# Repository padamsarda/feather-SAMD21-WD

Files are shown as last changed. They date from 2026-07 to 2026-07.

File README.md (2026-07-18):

# Feather SAMD21 MAX637X Watchdog dev board

A Feather-compatible development board based on the ATSAMD21G18A microcontroller with an integrated MAX6373 hardware watchdog for improving system reliability. The board retains the Adafruit Feather M0 Express footprint and pinout while incorporating USB Type-C connectivity, Li-Po battery charging, USB protection, and external clock circuitry. A 555 monostable circuit enables MCU power cycling, while multiple jumper options allow sections of the watchdog and reset circuitry to be enabled, disabled, or bypassed as required.

### Board at a glance

| Category | Hardware |
|---|---|
| MCU | ATSAMD21G18A |
| Hardware Watchdog | MAX6373 |
| USB | USB Type-C with USBLC6-2SC6 ESD protection |
| Battery Charging | MCP73832 |
| Voltage Regulation | AP2112K-3.3 (×2), LM5155xMM |
| Clock | 32.768 kHz crystal oscillator |
| Power Cycling | 555 monostable circuit |
| Expansion | Feather-compatible headers |

## MCU-WD Architecture

<p align="center">
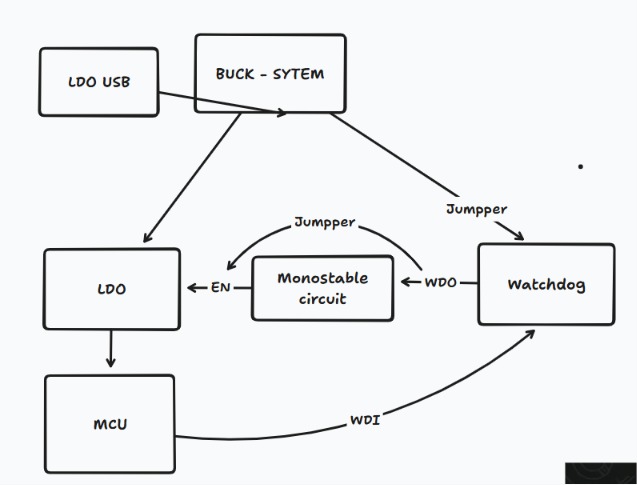
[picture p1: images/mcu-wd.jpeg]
MCU-WD Architecture
  <br>
  <em>High-level architecture of the Feather SAMD21 Watchdog board.</em>
</p>

## Schematic

Schematic

## PCB

<p align="center">
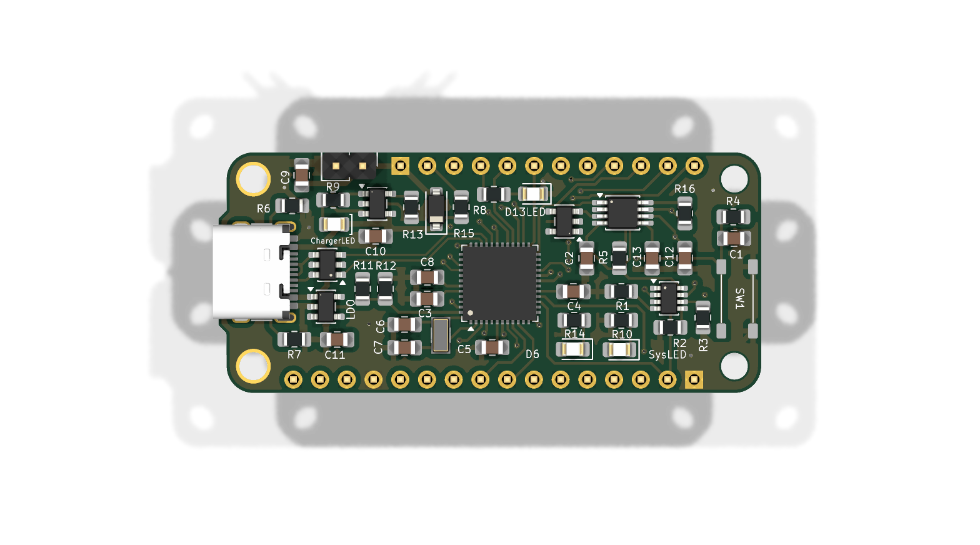
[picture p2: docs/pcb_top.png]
PCB Top
  
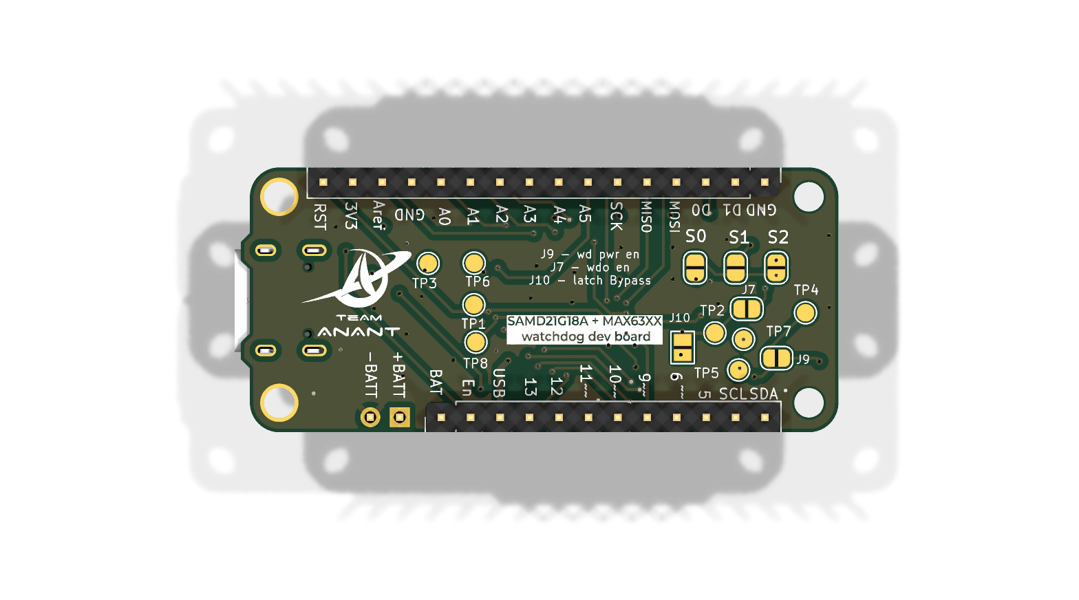
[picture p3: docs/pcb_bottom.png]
PCB Bottom
  
</p>

## Key Components

| Reference | Part | Function |
|---|---|---|
| U3 | ATSAMD21G18A-MU | Main microcontroller |
| U8 | MAX6373 | Hardware watchdog supervisor |
| U5 | MCP73832 | Li-Po battery charger |
| U2 | USBLC6-2SC6 | USB ESD protection |
| U4, U6 | AP2112K-3.3 | 3.3 V regulators |
| U7 | LM5155xMM | Power regulation |
| X1 | 32.768 kHz Crystal | External RTC clock source |
| D3 | BAT43W | Schottky diode |
| D2 | LED | Status indication |

## Connectors & I/O

| Reference | Interface | Description |
|---|---|---|
| J1 | JumperSET0 | Watchdog configuration |
| J2 | JumperSET1 | Watchdog configuration |
| J3 | JumperSET2 | Watchdog configuration |
| J4 | Left Feather Header | Feather-compatible expansion |
| J5 | Right Feather Header | Feather-compatible expansion |
| J6 | Battery Header | Li-Po battery connection |
| J7 | Reset Enable Jumper | Enable/disable reset path |
| J8 | USB Type-C | USB interface |
| J9 | WD_PWR Jumper | Watchdog power control |
| J10 | Monostable Bypass Jumper | Bypass 555 power-cycle circuit |

Designed and developed as part of **Team Anant**.

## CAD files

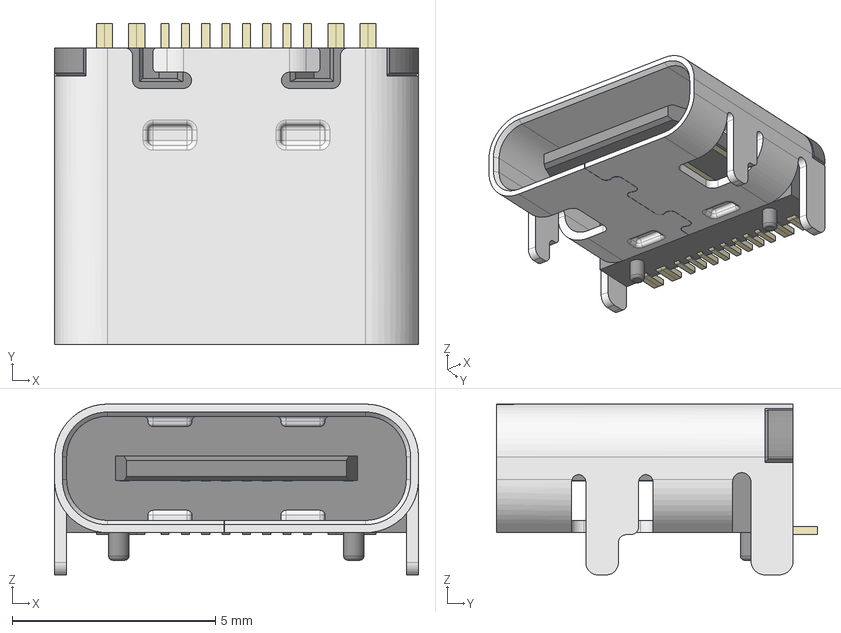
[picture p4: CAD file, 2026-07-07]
HRO_TYPE-C-31-M-12.step
8.95 x 7.90 x 4.20 mm

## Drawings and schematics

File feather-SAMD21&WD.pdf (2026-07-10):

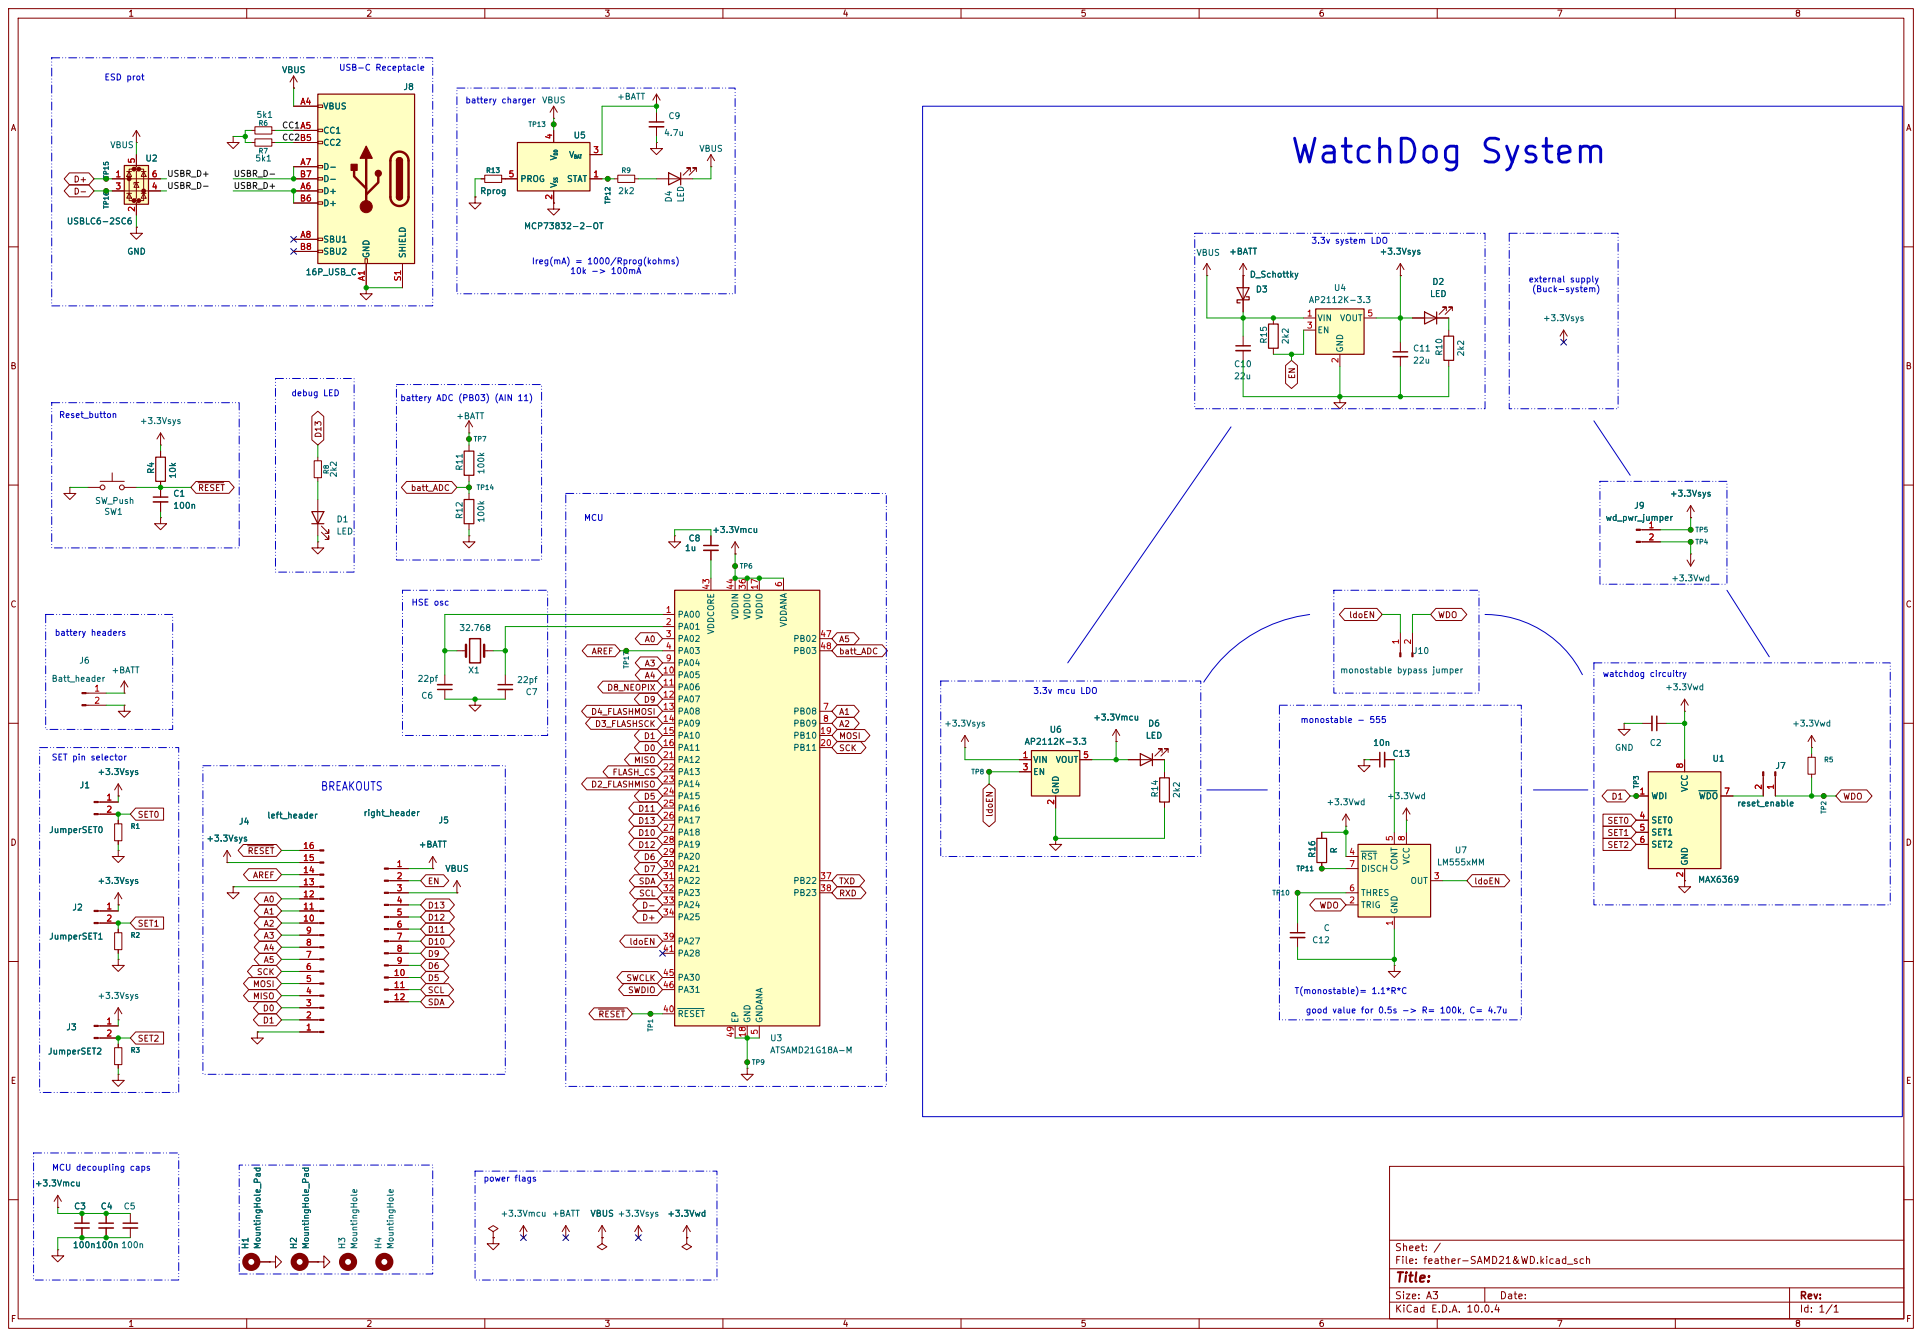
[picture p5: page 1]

Size: A3 | Rev:
KiCad E.D.A. 10.0.4 | Id: 1/1 | F Date:

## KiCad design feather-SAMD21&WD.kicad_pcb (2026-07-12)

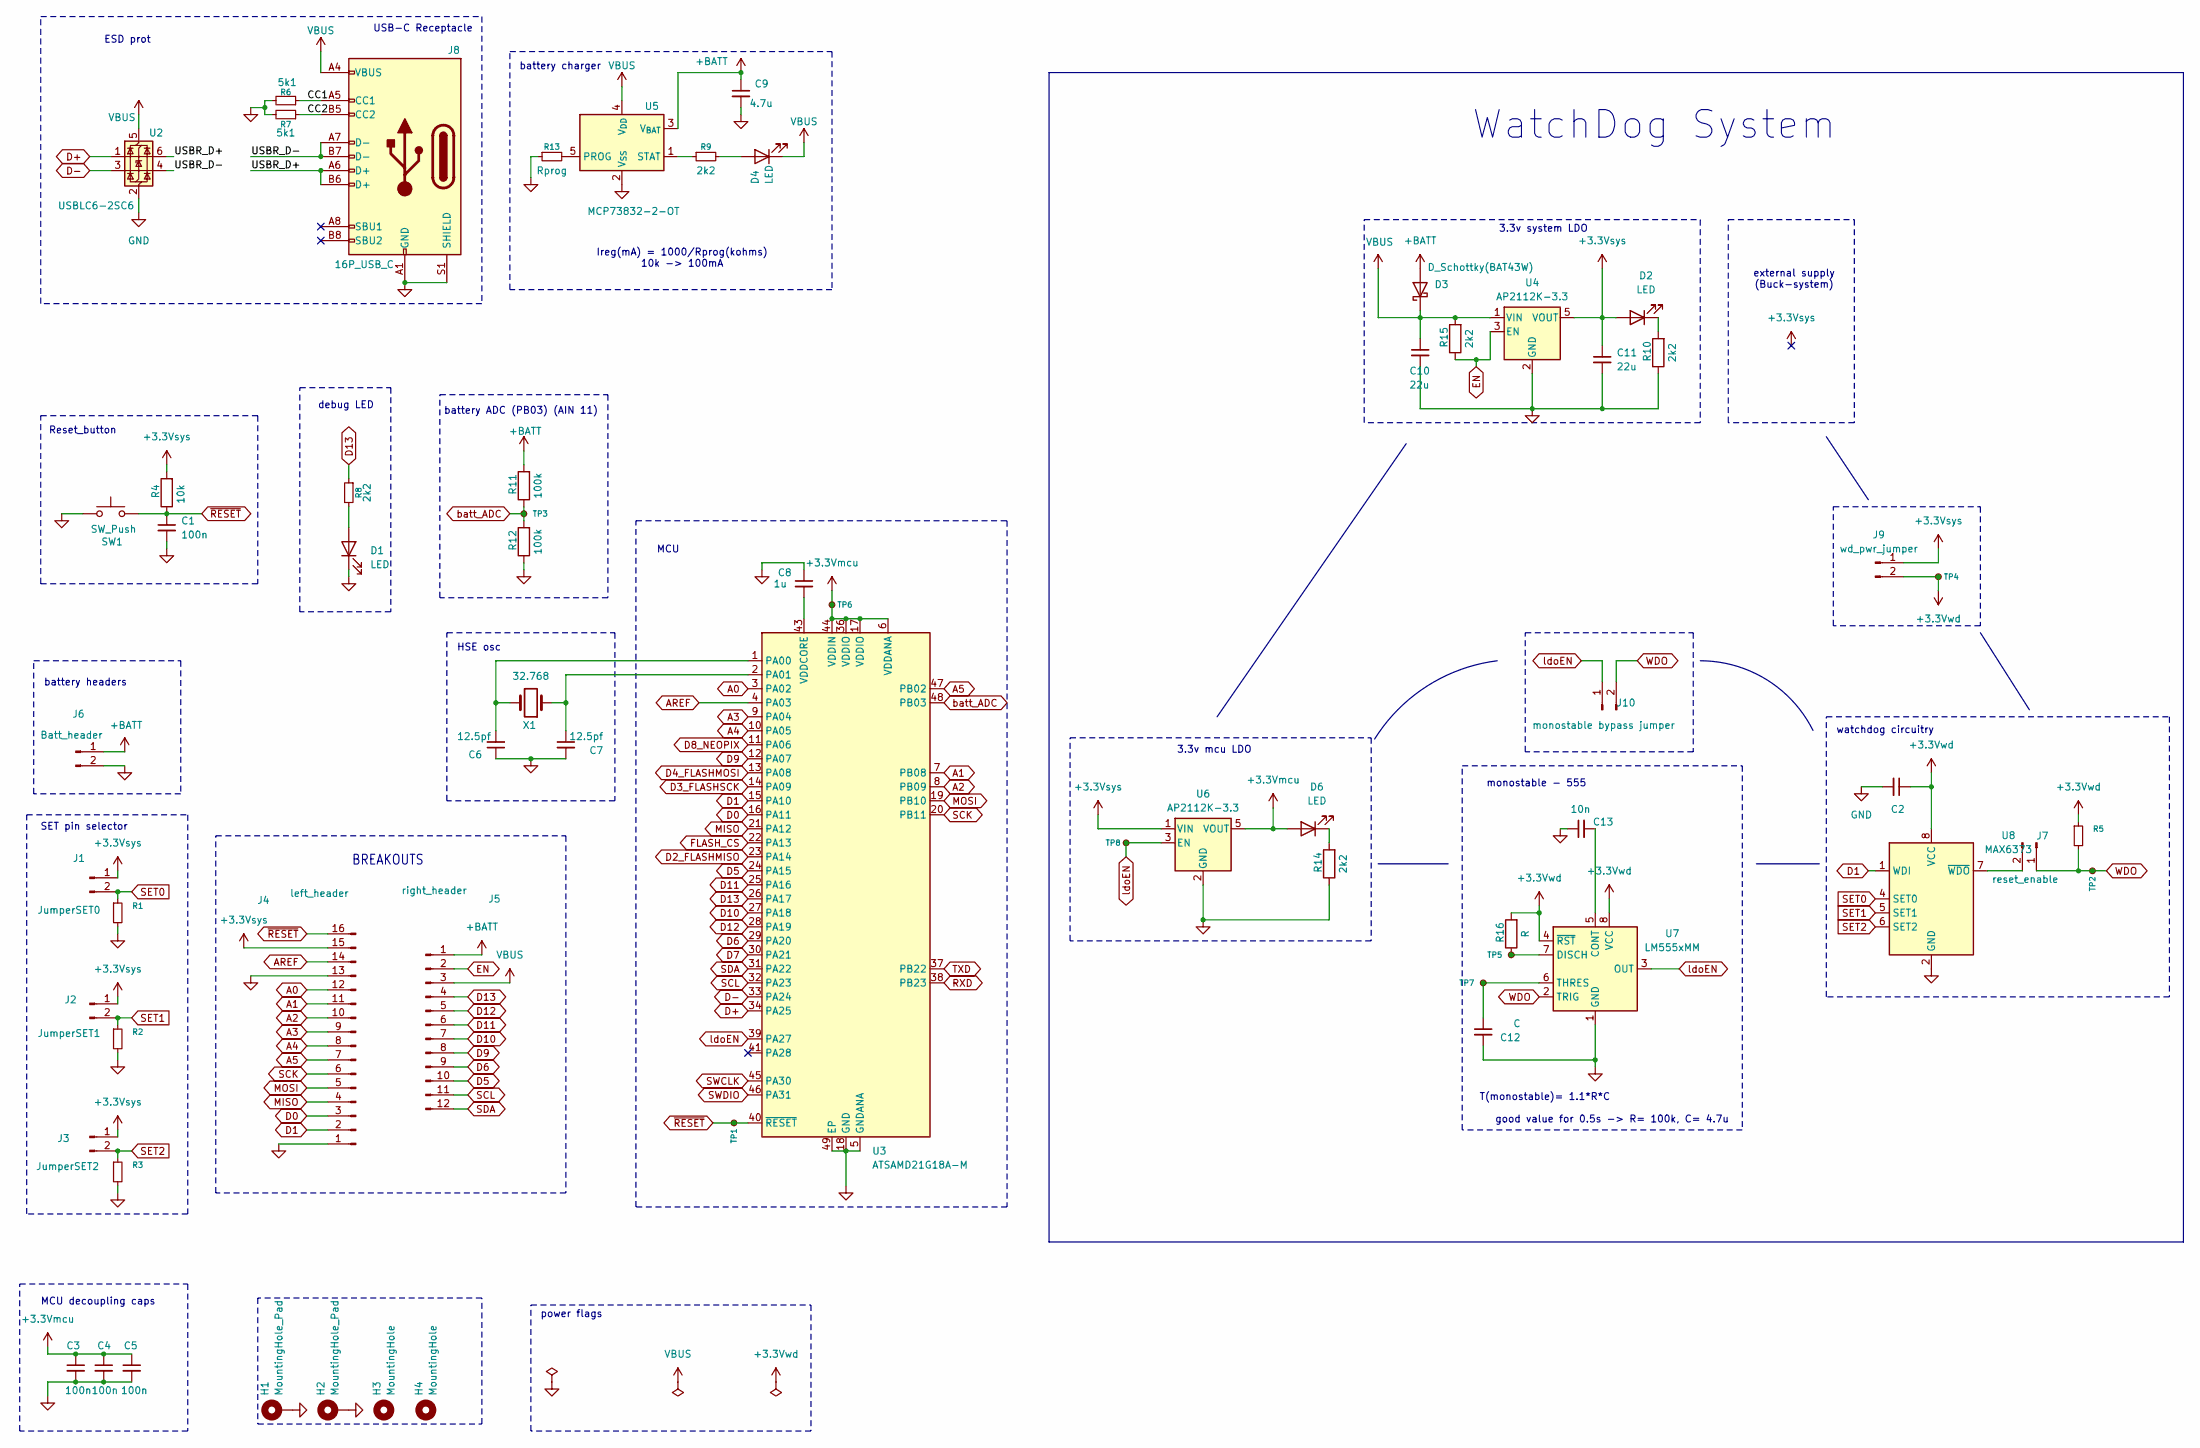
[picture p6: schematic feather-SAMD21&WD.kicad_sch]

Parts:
C1, C2, C3, C4, C5: 100n; C_0805_2012Metric_Pad1.18x1.45mm_HandSolder
C6, C7: 12.5pf; C_0805_2012Metric_Pad1.18x1.45mm_HandSolder
C8: 1u; C_0805_2012Metric_Pad1.18x1.45mm_HandSolder
C9: 4.7u; C_0805_2012Metric_Pad1.18x1.45mm_HandSolder
C10, C11: 22u; C_0805_2012Metric_Pad1.18x1.45mm_HandSolder
C12: C; C_0805_2012Metric_Pad1.18x1.45mm_HandSolder
C13: 10n; C_0805_2012Metric_Pad1.18x1.45mm_HandSolder
D1, D4: LED; LED_0805_2012Metric
D2, D6: LED; LED_0805_2012Metric_Pad1.15x1.40mm_HandSolder
D3: D_Schottky(BAT43W); D_SOD-123
H1, H2: MountingHole_Pad; feather_mounting hole M2.5
H3, H4: MountingHole; feather_mounting hole (no pad)
J1: JumperSET0; SolderJumper-2_P1.3mm_Open_RoundedPad1.0x1.5mm
J2: JumperSET1; SolderJumper-2_P1.3mm_Open_RoundedPad1.0x1.5mm
J3: JumperSET2; SolderJumper-2_P1.3mm_Open_RoundedPad1.0x1.5mm
J4: left_header; PinHeader_1x16_P2.54mm_Vertical
J5: right_header; PinHeader_1x12_P2.54mm_Vertical
J6: Batt_header; PinHeader_1x02_P2.54mm_Vertical
J7: reset_enable; SolderJumper-2_P1.3mm_Open_RoundedPad1.0x1.5mm
J8: 16P_USB_C; USB_C_Receptacle_G-Switch_GT-USB-7010ASV
J9: wd_pwr_jumper; SolderJumper-2_P1.3mm_Open_RoundedPad1.0x1.5mm
J10: monostable bypass jumper; SolderJumper-2_P1.3mm_Open_Pad1.0x1.5mm
R1, R2, R3, R5: R_Small; R_0805_2012Metric_Pad1.20x1.40mm_HandSolder
R4: 10k; R_0805_2012Metric_Pad1.20x1.40mm_HandSolder
R6, R7: 5k1; R_0805_2012Metric_Pad1.20x1.40mm_HandSolder
R8, R9, R10, R14, R15: 2k2; R_0805_2012Metric_Pad1.20x1.40mm_HandSolder
R11, R12: 100k; R_0805_2012Metric_Pad1.20x1.40mm_HandSolder
R13: Rprog; R_0805_2012Metric_Pad1.20x1.40mm_HandSolder
R16: R; R_0805_2012Metric_Pad1.20x1.40mm_HandSolder
SW1: SW_Push; tactile switch 4.5_4.5
TP1, TP2, TP3, TP4, TP5, TP6, TP7, TP8: TestPoint_Small; TestPoint_Pad_D1.5mm
U2: USBLC6-2SC6; SOT-23-6
U3: ATSAMD21G18A-M; QFN-48-1EP_7x7mm_P0.5mm_EP5.15x5.15mm
U4, U6: AP2112K-3.3; SOT-23-5
U5: MCP73832-2-OT; SOT-23-5
U7: LM555xMM; VSSOP-8_3x3mm_P0.65mm
U8: MAX6373; SOT-23-8
X1: 32.768; Crystal_SMD_3215-2Pin_3.2x1.5mm

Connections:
+3.3Vmcu: C3.1, C4.1, C5.1, D6.2 (A), TP6.1 (1_1), U3.6 (VDDANA), U3.17 (VDDIO), U3.36 (VDDIO), U3.44 (VDDIN), U6.5 (VOUT)
+3.3Vsys: C11.1, D2.2 (A), J1.1, J2.1, J3.1, J4.15, J9.1, R4.2, U4.5 (VOUT), U6.1 (VIN)
+3.3Vwd: C2.1, J9.2, R5.1, R16.2, TP4.1 (1_1), U7.4 (~RST), U7.8 (VCC), U8.8 (VCC); also elsewhere on the board
+BATT: C9.1, D3.2 (A), J5.1, J6.1, R11.2, U5.3 (V_{BAT})
/CC1: J8.A5 (CC1), R6.1
/CC2: J8.B5 (CC2), R7.1
/USBR_D+: J8.A6 (D+), J8.B6 (D+), U2.6 (I/O1)
/USBR_D-: J8.A7 (D-), J8.B7 (D-), U2.4 (I/O2)
A0: J4.12, U3.3 (PA02)
A1: J4.11, U3.7 (PB08)
A2: J4.10, U3.8 (PB09)
A3: J4.9, U3.9 (PA04)
A4: J4.8, U3.10 (PA05)
A5: J4.7, U3.47 (PB02)
AREF: J4.14, U3.4 (PA03)
D0: J4.3, U3.16 (PA11)
D1: J4.2, U3.15 (PA10), U8.1 (WDI); also elsewhere on the board
D2_FLASHMISO: U3.23 (PA14)
D3_FLASHSCK: U3.14 (PA09)
D4_FLASHMOSI: U3.13 (PA08)
D5: J5.10, U3.24 (PA15)
D6: J5.9, U3.29 (PA20)
D7: U3.30 (PA21)
D8_NEOPIX: U3.11 (PA06)
D9: J5.8, U3.12 (PA07)
D10: J5.7, U3.27 (PA18)
D11: J5.6, U3.25 (PA16)
D12: J5.5, U3.28 (PA19)
D13: J5.4, R8.1, U3.26 (PA17)
D+: U2.1 (I/O1), U3.34 (PA25)
D-: U2.3 (I/O2), U3.33 (PA24)
EN: J5.2, R15.1, U4.3 (EN)
FLASH_CS: U3.22 (PA13)
GND: C1.2, C2.2, C3.2, C4.2, C5.2, C6.1, C7.2, C8.1, C9.2, C10.2, C11.2, C12.2, C13.1, D1.1 (K), H1.1 (1_1), H2.1 (1_1), J4.1, J4.13, J6.2, J8.A1 (GND), J8.A12 (GND), J8.B1 (GND), J8.B12 (GND), J8.S1 (SHIELD), R1.2, R2.2, R3.2, R6.2, R7.2, R10.1, R12.1, R13.1, R14.1, SW1.1, U2.2 (GND), U3.5 (GNDANA), U3.18 (GND), U3.35 (GND), U3.42 (GND), U3.49 (EP), U4.2 (GND), U5.2 (V_{SS}), U6.2 (GND), U7.1 (GND), U8.2 (GND); also elsewhere on the board
MISO: J4.4, U3.21 (PA12)
MOSI: J4.5, U3.19 (PB10)
unnamed: D1.2 (A), R8.2
unnamed: D2.1 (K), R10.2
unnamed: D4.2 (A), R9.2
unnamed: D6.1 (K), R14.2
unnamed 40: J7.2, U8.7 (~WDO); also elsewhere on the board
unnamed: C6.2, U3.1 (PA00), X1.2
unnamed: C7.1, U3.2 (PA01), X1.1
unnamed: C8.2, U3.43 (VDDCORE)
unnamed: R13.2, U5.5 (PROG)
unnamed: R9.1, U5.1 (STAT)
unnamed: C13.2, U7.5 (CONT)
unnamed: R16.1, TP5.1 (1_1), U7.7 (DISCH)
unnamed: C12.1, TP7.1 (1_1), U7.6 (THRES)
RXD: U3.38 (PB23)
SCK: J4.6, U3.20 (PB11)
SCL: J5.11, U3.32 (PA23)
SDA: J5.12, U3.31 (PA22)
SET0: J1.2, R1.1, U8.4 (SET0); also elsewhere on the board
SET1: J2.2, R2.1, U8.5 (SET1); also elsewhere on the board
SET2: J3.2, R3.1, U8.6 (SET2); also elsewhere on the board
SWCLK: U3.45 (PA30)
SWDIO: U3.46 (PA31)
TXD: U3.37 (PB22)
VBUS: C10.1, D3.1 (K), D4.1 (K), J5.3, J8.A4 (VBUS), J8.A9 (VBUS), J8.B4 (VBUS), J8.B9 (VBUS), R15.2, U2.5 (VBUS), U4.1 (VIN), U5.4 (V_{DD})
WDO: J7.1, J10.2, R5.2, TP2.1 (1_1), U7.2 (TRIG)
batt_ADC: R11.1, R12.2, TP3.1 (1_1), U3.48 (PB03)
ldoEN: J10.1, TP8.1 (1_1), U3.39 (PA27), U6.3 (EN), U7.3 (OUT)
~RESET: C1.1, J4.16, R4.1, SW1.2, TP1.1 (1_1), U3.40 (~RESET)

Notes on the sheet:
BREAKOUTS
watchdog circuitry
battery ADC (PB03) (AIN 11)
MCU decoupling caps
3.3v system LDO
Reset_button
MCU
HSE osc
power flags
battery headers
3.3v mcu LDO
good value for 0.5s -> R= 100k, C= 4.7u
monostable - 555
battery charger
ESD prot
Ireg(mA) = 1000/Rprog(kohms) 10k -> 100mA
debug LED
T(monostable)= 1.1*R*C
SET pin selector
WatchDog System
USB-C Receptacle
external supply (Buck-system)

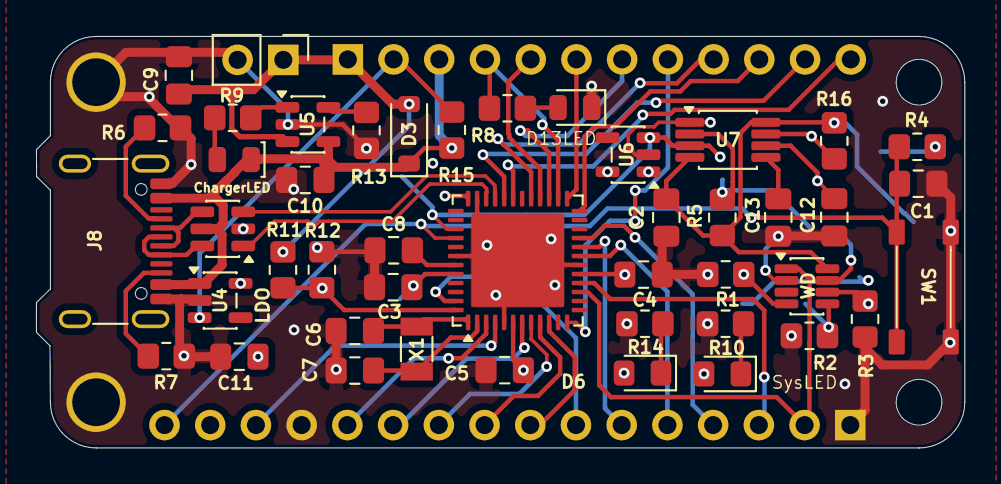
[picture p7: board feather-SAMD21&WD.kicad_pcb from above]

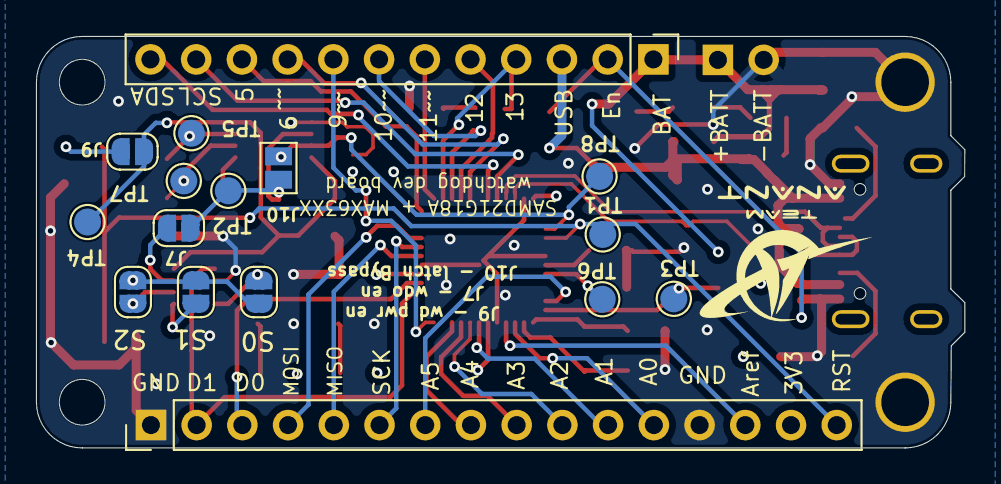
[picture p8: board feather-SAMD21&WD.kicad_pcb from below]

Board: 4 copper layers, 51.6 x 22.9 mm, 65 parts (16 on the bottom side), 54 nets.

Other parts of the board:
WD: MAX6373; SOT-23-8

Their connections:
+3.3Vwd: WD.8 (VCC); also elsewhere on the board
D1: WD.1 (WDI); also elsewhere on the board
GND: WD.2 (GND); also elsewhere on the board
unnamed 40: WD.7 (~WDO); also elsewhere on the board
SET0: WD.4 (SET0); also elsewhere on the board
SET1: WD.5 (SET1); also elsewhere on the board
SET2: WD.6 (SET2); also elsewhere on the board

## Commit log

2026-07-06 initial commit, sch only
    [feather-SAMD21&WD.kicad_pcb, feather-SAMD21&WD.kicad_sch]
2026-07-06 minor changes
    [feather-SAMD21&WD.kicad_sch]
2026-07-07 layout done, few sch changes
    [HRO_TYPE-C-31-M-12.step, feather-SAMD21&WD.kicad_pcb, feather-SAMD21&WD.kicad_sch]
2026-07-07 rev one, routing done
    [feather-SAMD21&WD.kicad_pcb, feather-SAMD21&WD.kicad_sch]
2026-07-09 V3 schematic updated
    [feather-SAMD21&WD.kicad_pcb, feather-SAMD21&WD.kicad_sch]
2026-07-09 v3 layout done
    [feather-SAMD21&WD.kicad_pcb, feather-SAMD21&WD.kicad_sch]
2026-07-10 final changes, everythings done
    [feather-SAMD21&WD.kicad_pcb, feather-SAMD21&WD.kicad_sch]
2026-07-10 adding images
    [feather-SAMD21&WD.kicad_pcb]
2026-07-10 finishing touches
    [feather-SAMD21&WD.kicad_pcb, feather-SAMD21&WD.kicad_sch]
